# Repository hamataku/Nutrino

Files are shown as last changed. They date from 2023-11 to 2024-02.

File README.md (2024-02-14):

# Nutrino
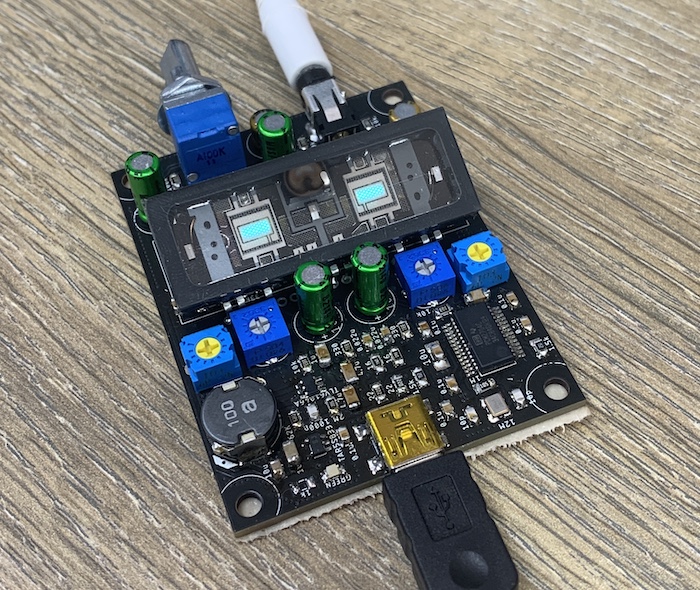
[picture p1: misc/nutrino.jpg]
Nutrino


**Nutrino** is a USB headphone amplifier featuring the application of the **Nutube**. It incorporates the PCM2704 as the codec IC and utilizes the NJM4580 for the operational amplifier in the output stage.

The circuit design was completed using Eagle. The schematic diagram is [here](misc/nutrino.pdf).

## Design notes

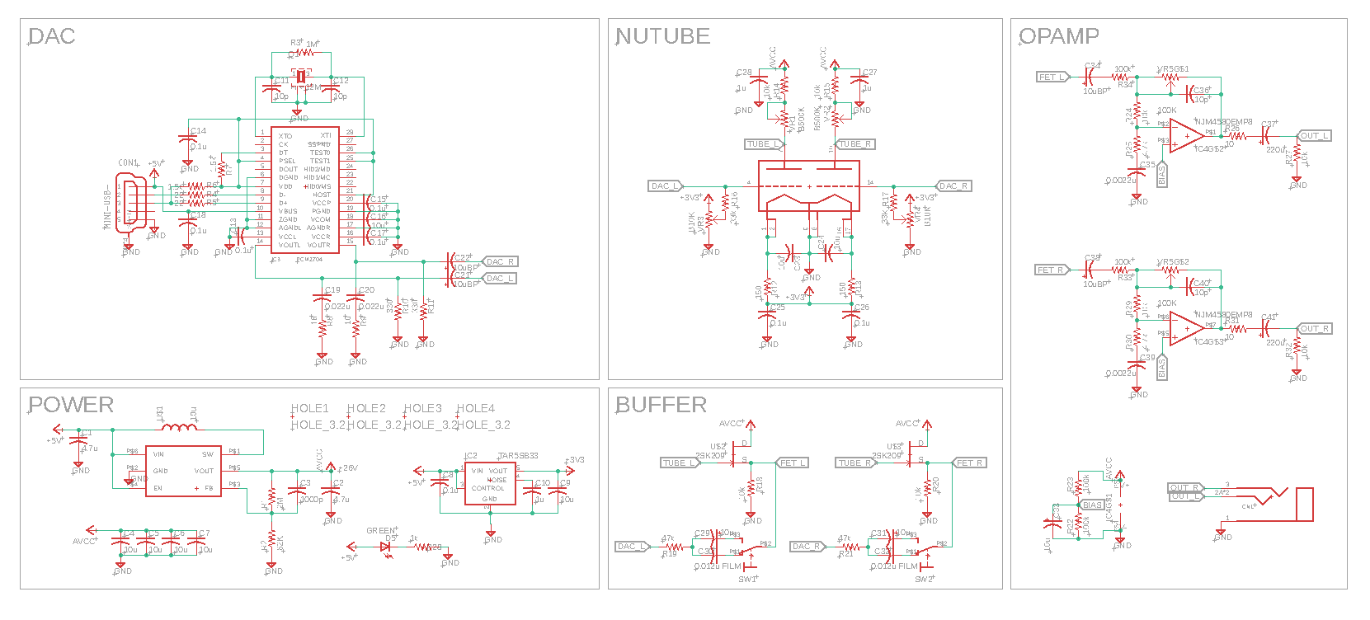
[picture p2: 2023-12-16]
misc/schematic.png

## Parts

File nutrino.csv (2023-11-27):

Qty | Value | Device | Package | Parts | Description
1 |  | NUTUBE_6P1_1 | NUTUBE_6P1_1 | U1 | NUTUBE 6P1 Twin Triode
2 | 0.0022u | C-2012 | 2012-C | C35, C39
2 | 0.012u FILM | C/5 | C050-024X044 | C30, C32
2 | 0.022u | C-2012 | 2012-C | C19, C20
8 | 0.1u | C-2012 | 2012-C | C8, C13, C14, C15, C17, C18, C25, C26
2 | 1.5k | R-2012 | 2012-R | R6, R7
2 | 10 | R-4532 | 4532 | R26, R31
1 | 1000p | C-2012 | 2012-C | C3
1 | 100K | VR2C | VR2C | VR5
4 | 100k | R-2012 | 2012-R | R22, R23, R33, R34
8 | 10k | R-2012 | 2012-R | R14, R15, R18, R20, R24, R27, R29, R32
4 | 10p | C-2012 | 2012-C | C11, C12, C36, C40
5 | 10u | C-2012 | 2012-C | C4, C5, C6, C7, C9
3 | 10u | C-3216 | 3216 | C16, C23, C24
3 | 10u | CC-2.5-7 | E2,5-7 | C29, C31, C33
1 | 10u | INDUCTOR-NR10050T | NR10050T | U$1 | Inductors
4 | 10uBP | CC-2.5-7 | E2,5-7 | C21, C22, C34, C38
1 | 12M | FA-238V | FA-238V | Q1 | MHz RANGE CRYSTAL UNIT
2 | 150 | R-2012 | 2012-R | R12, R13
2 | 16 | R-2012 | 2012-R | R8, R9
1 | 1M | R-2012 | 2012-R | R3
1 | 1k | R-2012 | 2012-R | R28
3 | 1u | C-2012 | 2012-C | C10, C27, C28
2 | 22 | R-2012 | 2012-R | R4, R5
2 | 220u | CC-2.5-7 | E2,5-7 | C37, C41
1 | 2M | R-2012 | 2012-R | R1
2 | 2SK209 | 2SK209 | SC59 | U$2, U$3
2 | 330 | R-2012 | 2012-R | R10, R11
2 | 33k | R-2012 | 2012-R | R16, R17
2 | 4.7k | R-2012 | 2012-R | R25, R30
2 | 4.7u | C-2012 | 2012-C | C1, C2
2 | 47k | R-2012 | 2012-R | R19, R21
1 | 62K | R-2012 | 2012-R | R2
2 | B10K | VR2 | VR2 | VR3, VR4
2 | B500K | VR2 | VR2 | VR1, VR2
1 | GREEN | LED-SMD2012 | D2012 | D5
4 | HOLE_3.2 | HOLE_3.2 | HOLE_3.2 | HOLE1, HOLE2, HOLE3, HOLE4 | Robotechhole diameter 3.2mmtDoc washer(diameter 8mm)bDoc spacer(diameter 6mm)
1 | MINI-USB- | MINI-USB- | UX60A-MB-5ST | CON1 | MINI USB Connector
1 | NJM4580EMP8 | NJM4580EMP8 | EMP8 | IC4
1 | PCM2704 | PCM2704 | SSOP28 | IC3
2 | SLIDESW_SS12D01G4 | SLIDESW_SS12D01G4 | SS12D01G4 | SW1, SW2 | Slide Switch
1 | STEREO-3.5-MJ8435 | STEREO-3.5-MJ8435 | MJ8435 | CN1
1 | TAR5SB33 | TAR5SB33 | SSOP5-P-0.95 | IC2 | Voltage Regulator max 200mA.
1 | TLV61046A | TLV61046A | SOT23-6 | IC1

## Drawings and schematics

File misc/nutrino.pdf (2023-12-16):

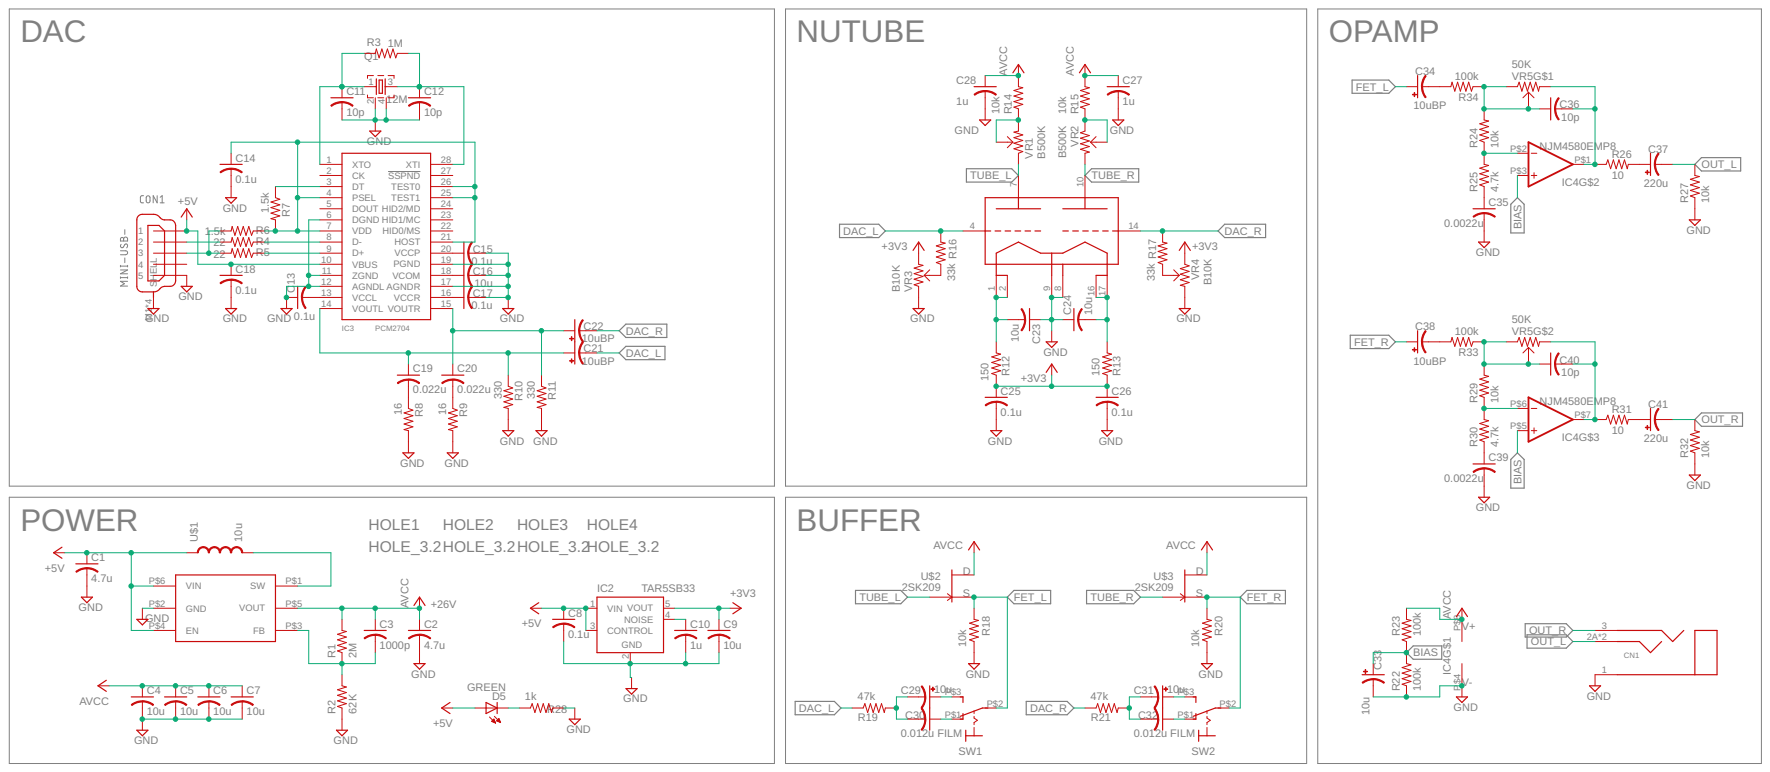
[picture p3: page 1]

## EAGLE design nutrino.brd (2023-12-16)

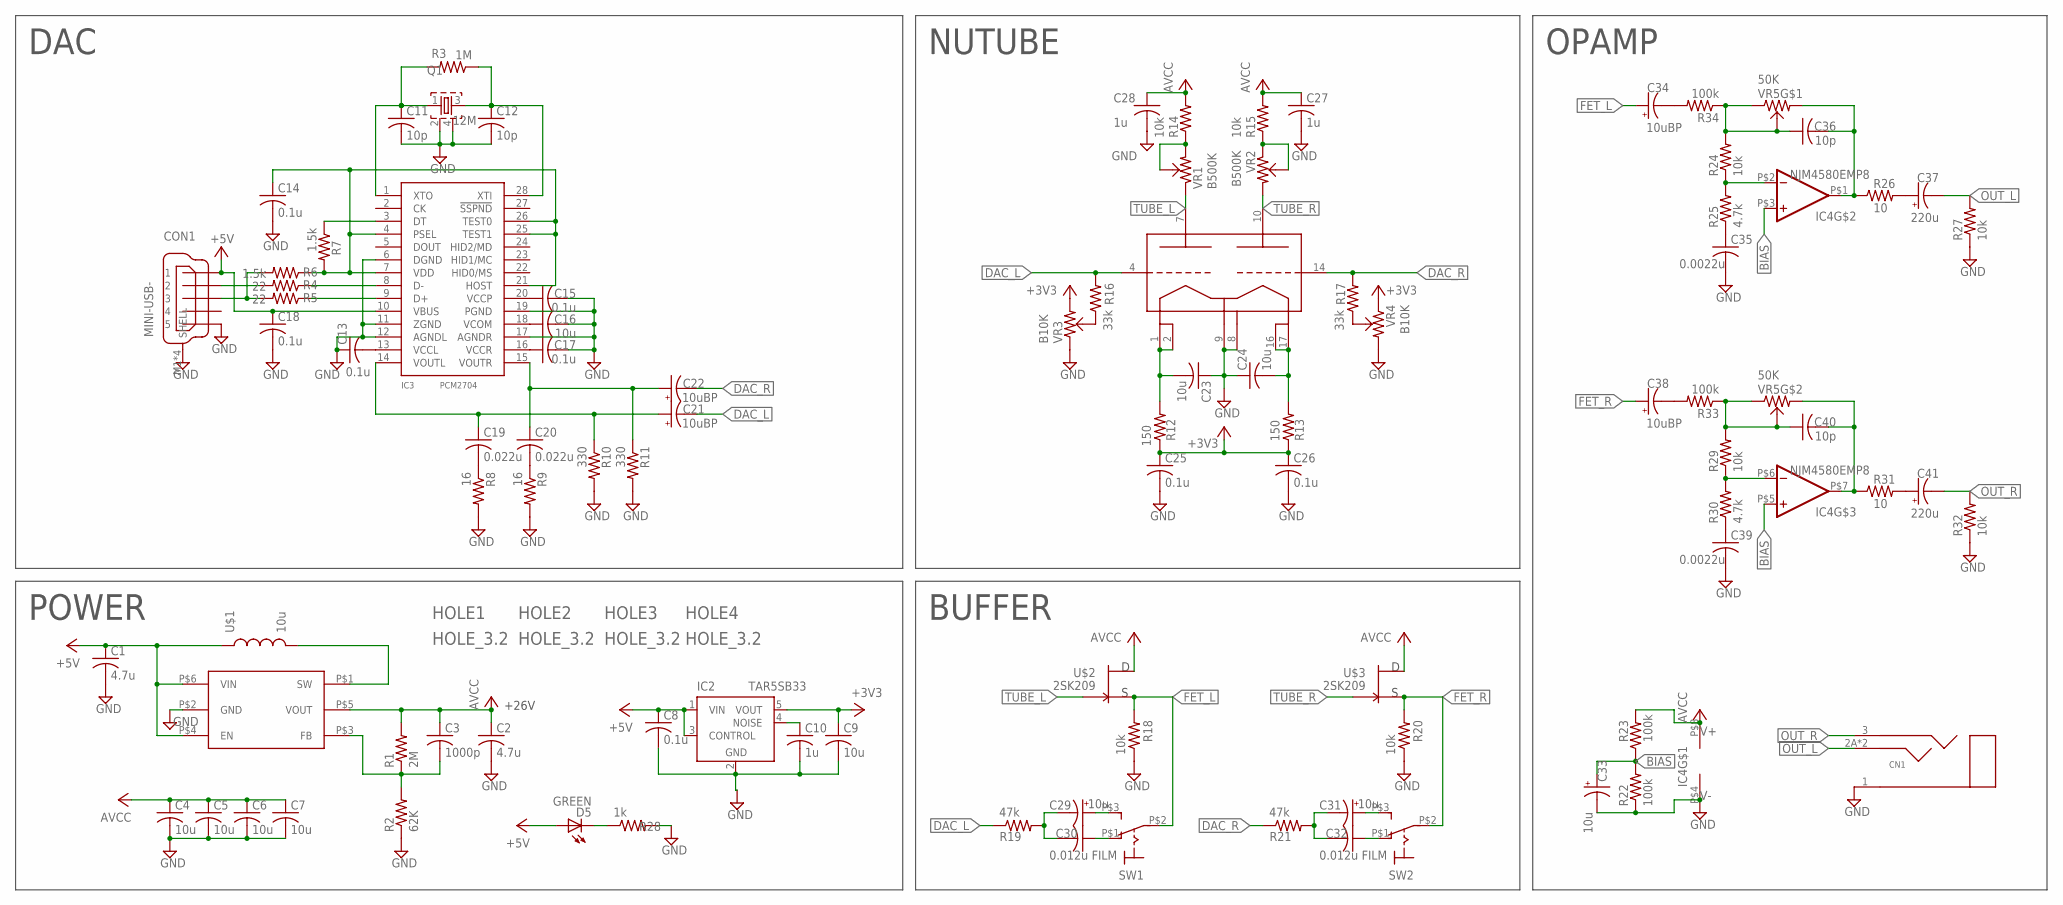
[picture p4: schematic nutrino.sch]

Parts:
C1, C2: 4.7u; 2012-C
C3: 1000p; 2012-C
C4, C5, C6, C7, C9: 10u; 2012-C
C8, C13, C14, C15, C17, C18, C25, C26: 0.1u; 2012-C
C10, C27, C28: 1u; 2012-C
C11, C12, C36, C40: 10p; 2012-C
C16, C23, C24: 10u; 3216
C19, C20: 0.022u; 2012-C
C21, C22, C34, C38: 10uBP; E2,5-7
C29, C31, C33: 10u; E2,5-7
C30, C32: 0.012u FILM; C050-024X044
C35, C39: 0.0022u; 2012-C
C37, C41: 220u; E2,5-7
CN1: STEREO-3.5-MJ8435; MJ8435
CON1: MINI-USB-; UX60A-MB-5ST
D5: GREEN; D2012
HOLE1, HOLE2, HOLE3, HOLE4: HOLE_3.2
IC1: TLV61046A; SOT23-6
IC2: TAR5SB33; SSOP5-P-0.95
IC3: PCM2704; SSOP28
IC4: NJM4580EMP8; EMP8
Q1: 12M; FA-238V
R1: 2M; 2012-R
R2: 62K; 2012-R
R3: 1M; 2012-R
R4, R5: 22; 2012-R
R6, R7: 1.5k; 2012-R
R8, R9: 16; 2012-R
R10, R11: 330; 2012-R
R12, R13: 150; 2012-R
R14, R15, R18, R20, R24, R27, R29, R32: 10k; 2012-R
R16, R17: 33k; 2012-R
R19, R21: 47k; 2012-R
R22, R23, R33, R34: 100k; 2012-R
R25, R30: 4.7k; 2012-R
R26, R31: 10; 4532
R28: 1k; 2012-R
SW1, SW2: SLIDESW_SS12D01G4; SS12D01G4
U1: NUTUBE_6P1_1
U$1: 10u; NR10050T
U$2, U$3: 2SK209; SC59
VR1, VR2: B500K; VR2
VR3, VR4: B10K; VR2
VR5: 50K; VR2C

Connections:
+3V3: C9.1, C25.1, C26.1, IC2.5 (VOUT), R12.1, R13.1, VR3.2, VR4.1
+5V: C1.1, C8.1, C18.1, CON1.1, D5.A, IC1.P$4 (EN), IC1.P$6 (VIN), IC2.1 (VIN), IC2.3 (CONTROL), IC3.10 (VBUS), U$1.1
AVCC: C2.1, C3.1, C4.1, C5.1, C6.1, C7.1, C27.1, C28.1, IC1.P$5 (VOUT), IC4.P$8 (V+), R1.2, R14.2, R15.2, R23.2, U$2.E (D), U$3.E (D)
BIAS: C33.+, IC4.P$3 (+IN), IC4.P$5 (+IN), R22.2, R23.1
DAC_L: C21.-, R16.2, R19.1, U1.4 (G1_4)
DAC_R: C22.-, R17.2, R21.1, U1.14 (G2_14)
FET_L: C34.+, R18.2, SW1.P$2, U$2.B (S)
FET_R: C38.+, R20.2, SW2.P$2, U$3.B (S)
GND: C1.2, C2.2, C4.2, C5.2, C6.2, C7.2, C8.2, C9.2, C10.2, C11.2, C12.2, C13.1, C14.2, C15.2, C16.2, C17.2, C18.2, C23.1, C24.1, C25.2, C26.2, C27.2, C28.2, C33.-, C35.2, C39.2, CN1.1 (SLEEVE), CON1.5, CON1.M1 (SHELL), CON1.M2 (SHELL), CON1.M3 (SHELL), CON1.M4 (SHELL), IC1.P$2 (GND), IC2.2 (GND), IC3.6 (DGND), IC3.11 (ZGND), IC3.12 (AGNDL), IC3.17 (AGNDR), IC3.19 (PGND), IC4.P$4 (V-), Q1.2, Q1.4, R2.1, R8.2, R9.2, R10.2, R11.2, R18.1, R20.1, R22.1, R27.1, R28.2, R32.1, U1.8 (GND_8), U1.9 (F2_9), VR3.1, VR4.2
unnamed: C11.1, IC3.1 (XTO), Q1.1, R3.2
unnamed: IC1.P$1 (SW), U$1.2
unnamed: C12.1, IC3.28 (XTI), Q1.3, R3.1
unnamed: C3.2, IC1.P$3 (FB), R1.1, R2.2
unnamed: IC3.9 (D+), R5.1
unnamed: IC3.8 (D-), R4.1
unnamed: CON1.2, R4.2
unnamed: CON1.3, R5.2, R6.2
unnamed: C13.2, IC3.13 (VCCL)
unnamed: C14.1, IC3.4 (PSEL), IC3.7 (VDD), IC3.21 (HOST), IC3.25 (TEST1), IC3.26 (TEST0), R6.1, R7.2
unnamed: C15.1, IC3.20 (VCCP)
unnamed: C17.1, IC3.16 (VCCR)
unnamed: C16.1, IC3.18 (VCOM)
unnamed: C19.2, R8.1
unnamed: IC3.3 (DT), R7.1
unnamed: C20.2, R9.1
unnamed: C20.1, C22.+, IC3.15 (VOUTR), R11.1
unnamed: C19.1, C21.+, IC3.14 (VOUTL), R10.1
unnamed: D5.K, R28.1
unnamed: R14.1, VR1.2, VR1.BR
unnamed: C10.1, IC2.4 (NOISE)
unnamed: C24.2, R13.2, U1.16 (F3_16), U1.17 (F3_17)
unnamed: C23.2, R12.2, U1.1 (F1_1), U1.2 (F1_2)
unnamed: C30.1, SW1.P$1 (O)
unnamed: C29.+, SW1.P$3 (S)
unnamed: R15.1, VR2.1, VR2.BR
unnamed: R16.1, VR3.BR
unnamed: R17.1, VR4.BR
unnamed: C32.1, SW2.P$1 (O)
unnamed: C31.+, SW2.P$3 (S)
unnamed: C29.-, C30.2, R19.2
unnamed: IC4.P$2 (-IN), R24.1, R25.2
unnamed: C35.1, R25.1
unnamed: C36.1, R24.2, R34.1, VR5.2 (BR), VR5.3 (1)
unnamed: C34.-, R34.2
unnamed: C36.2, IC4.P$1 (OUT), R26.1, VR5.1 (2)
unnamed: C31.-, C32.2, R21.2
unnamed: C37.+, R26.2
unnamed: IC4.P$6 (-IN), R29.1, R30.2
unnamed: C39.1, R30.1
unnamed: C40.1, R29.2, R33.1, VR5.2' (BR), VR5.3' (1)
unnamed: C38.-, R33.2
unnamed: C40.2, IC4.P$7 (OUT), R31.1, VR5.1' (2)
unnamed: C41.+, R31.2
OUT_L: C37.-, CN1.2A (RING), CN1.2B (RING), R27.2
OUT_R: C41.-, CN1.3 (TIP), R32.2
TUBE_L: U1.7 (A1_7), U$2.C (G), VR1.1
TUBE_R: U1.10 (A2_10), U$3.C (G), VR2.2

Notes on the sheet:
POWER
DAC
+26V
NUTUBE
BUFFER
OPAMP

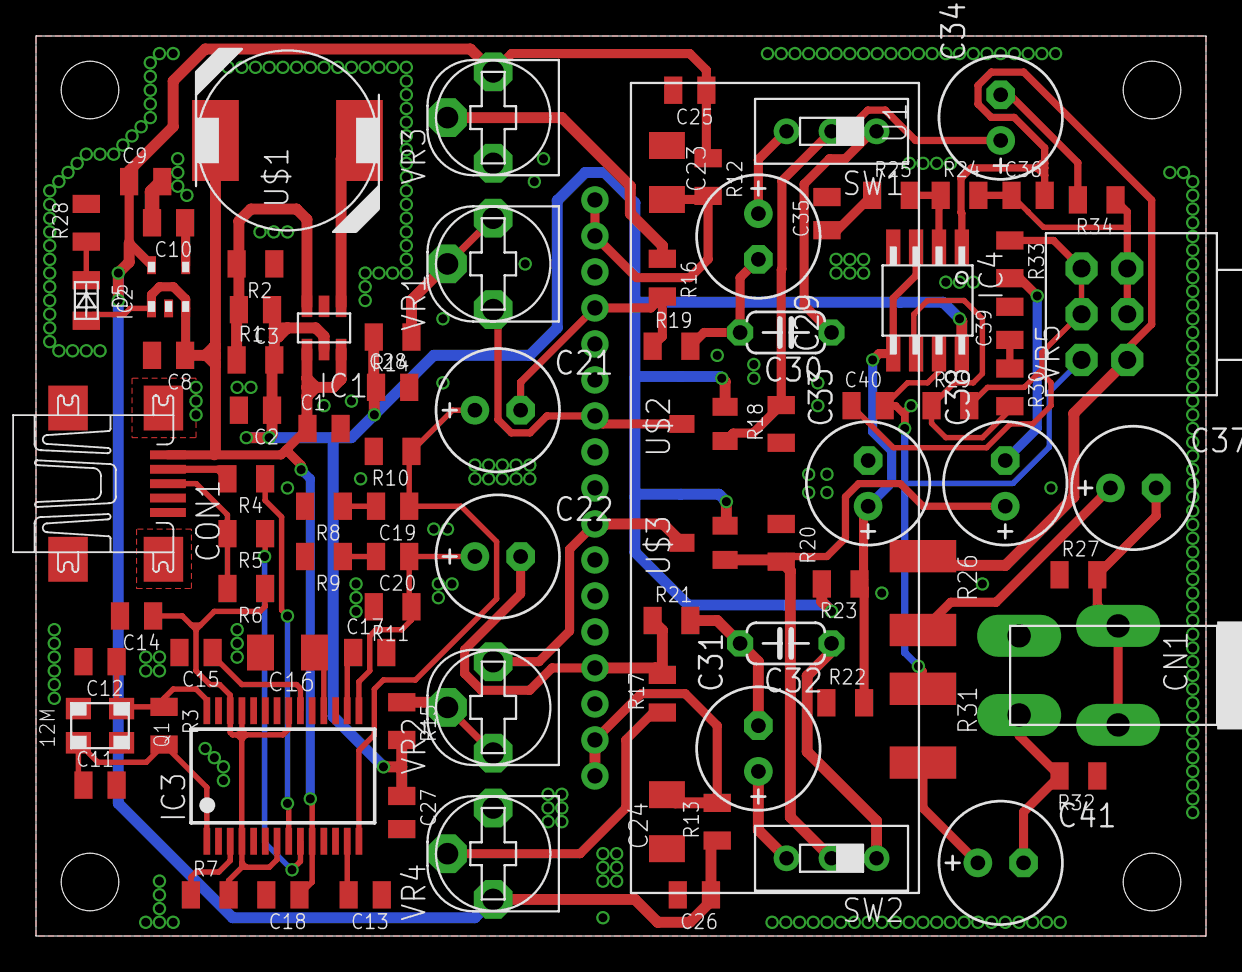
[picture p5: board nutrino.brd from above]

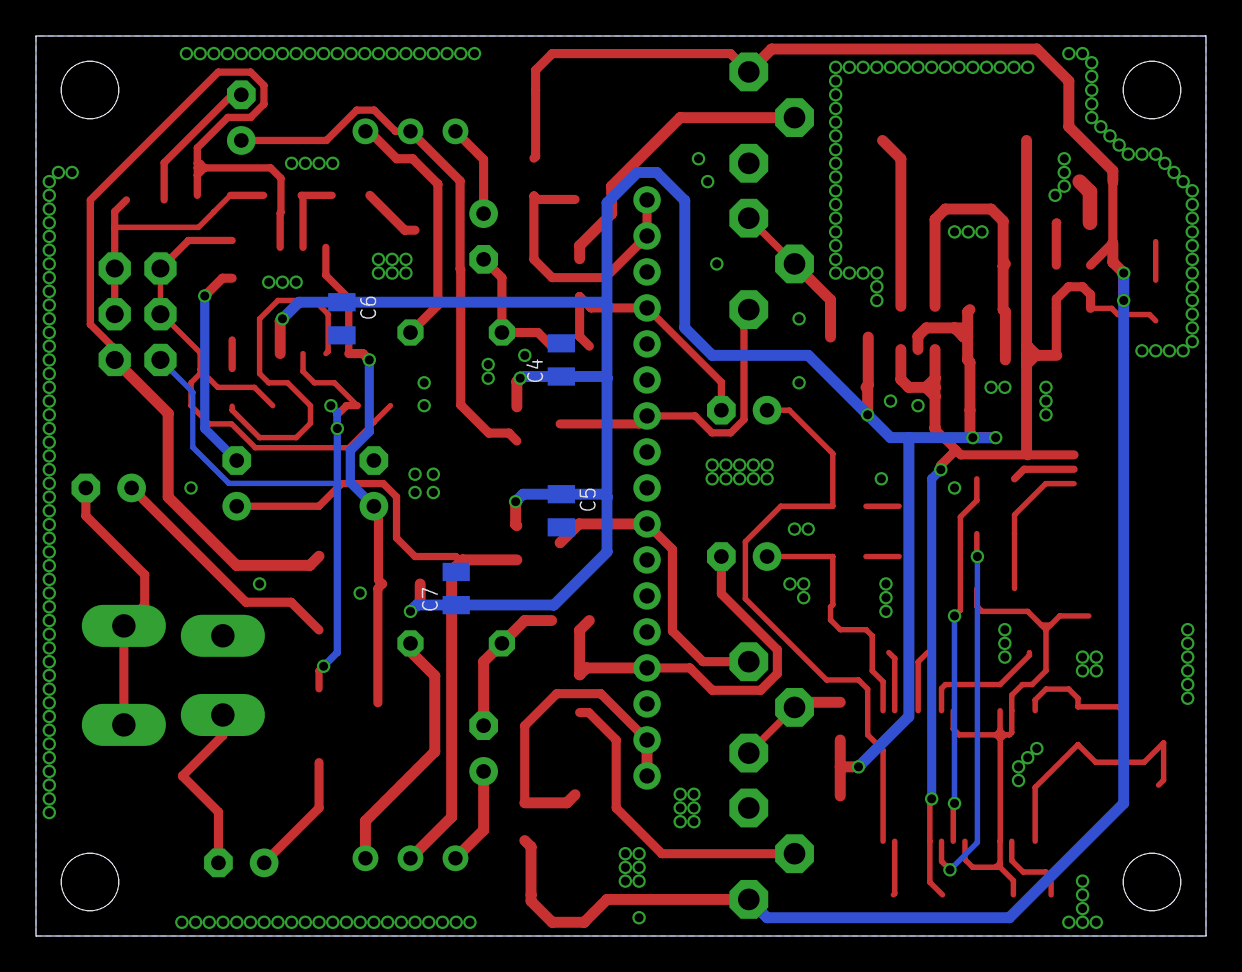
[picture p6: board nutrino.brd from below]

Board: 2 copper layers, 65.0 x 50.0 mm, 98 parts (4 on the bottom side), 57 nets.

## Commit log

2023-10-08 designed schematic
    [nutrino.brd, nutrino.sch]
2023-10-09 placed parts
    [nutrino.brd, nutrino.sch]
2023-10-09 Board diagram completed
    [nutrino.brd, nutrino.sch]
2023-11-27 add image
    [nutrino.brd, nutrino.csv, nutrino.sch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]
2023-12-16 add schematic pdf
    [nutrino_all.csv]
2023-12-16 update schematic
    [nutrino.brd, nutrino.sch]
